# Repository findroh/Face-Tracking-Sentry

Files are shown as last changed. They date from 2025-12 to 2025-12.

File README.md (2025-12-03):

# Face-Tracking-Sentry
An automated sentry using a Raspberry Pi, ESP32, and two 9g servo motors along with a PiCamera 2 to perform facial detection, recognition, and tracking.
The control is split into two parts, image processing which is handled on the Raspberry Pi, and motor control which is handled by the ESP32-C3.
Due to the Raspberry Pi 4's relatively low processing power for tasks such as facial recognition, a finite state machine system is utilized to mitigate these issues.
The program initially starts in the detect state, which runs a continuous loop on standby until HaarCascades detects a face in the camera view. 
Once detection is achieved, the program then goes into the recognition state, this utilizes the facial recognition library to check the detected face against a file of pictures of labeled faces in the Pi's storage.
When recognition is completed an output of either the recognized faces name will be printed on the console, if the face is not recognized, "Unknown" will be printed on the console.
After this stage is completed, the system now goes to the Tracking state, this takes the same bounding box from the detection state and applies it as a boundary for a MOSSE tracker. 
The MOSSE tracker allows us to track a subjects face while also not losing our bounding box due to head movements such as turning the head to the side, up, or down.
The system will continue to stay in tracking mode until tracking is lost, which will cause the state machine to restart.
During the detection and tracking states, the coordinates of the center poitn of the bounding box are sent via USB serial communication to the EPS32.
These coordinates are used to calculate the error the bounding box to the center of the camera view.
I used this calculated error to control two servo motors in a PID control loop, with a seperate error calculation for the x and y axes. 
This allows the camera to have a quicker and more accurate response to the subject in the camera view.

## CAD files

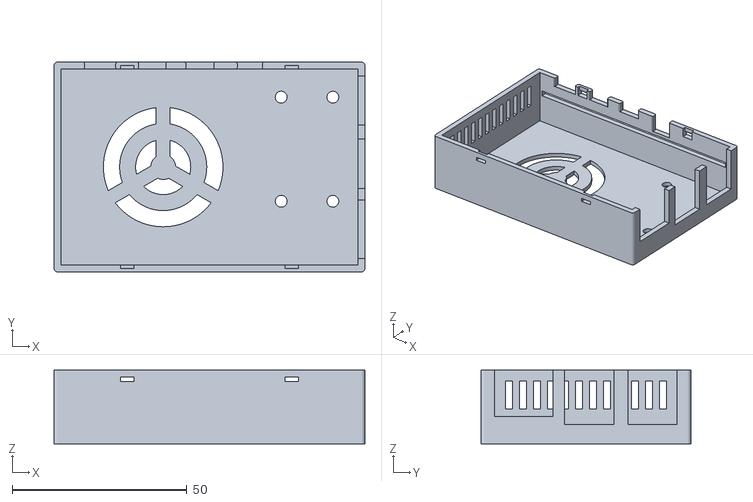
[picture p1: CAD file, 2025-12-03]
PiCase_Top.stl
89.0 x 60.0 x 21.1

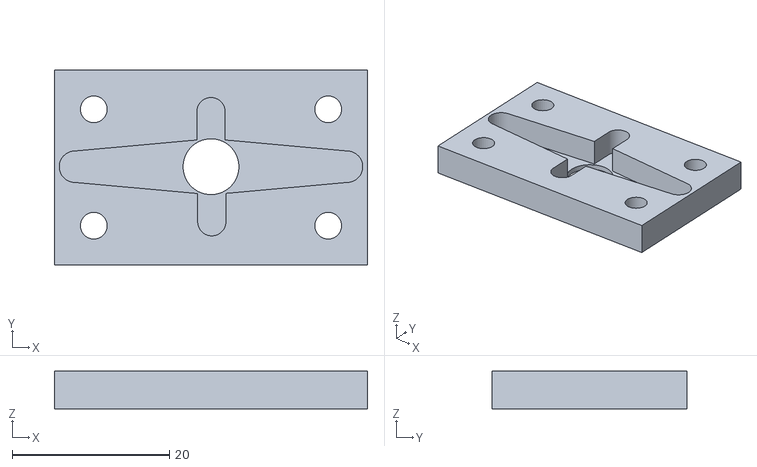
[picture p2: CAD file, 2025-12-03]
BasePlate_Revised.stl
39.8 x 24.8 x 4.80

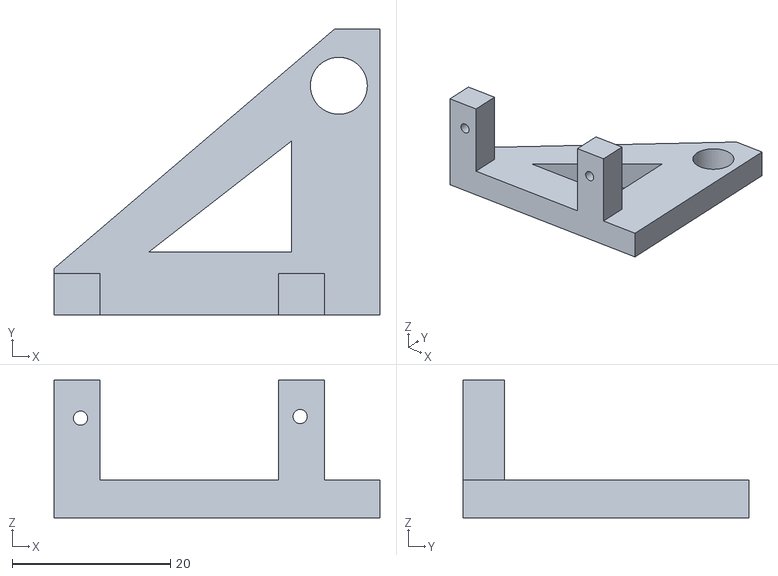
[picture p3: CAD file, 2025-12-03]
Mounting bracket V4.stl
41.2 x 36.2 x 17.4

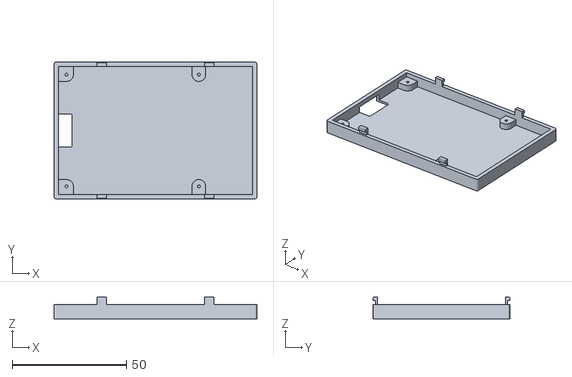
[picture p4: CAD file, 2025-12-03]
PiCaseBottom6-Fillet.stl
89.0 x 60.0 x 9.52

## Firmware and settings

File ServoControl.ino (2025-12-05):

#include <ESP32Servo.h>
#include <math.h>
Servo servoX;
Servo servoY;
int servoPinX = 6;
int servoPinY = 5;
int currentAngle_X = 90;
int currentAngle_Y = 90;
double Kp = 0.03;
double Ki = 0.0004;
double Kd = 0.5;
double dt = 0;
double previousTime = 0;
double integral = 0;
double previousError = 0;
void setup() {
  // put your setup code here, to run once:

 Serial.begin(115200);
 Serial.println("ESP32 Ready to Receive");
 servoX.attach(servoPinX);
 servoY.attach(servoPinY);
 servoX.write(currentAngle_X);
 servoY.write(currentAngle_Y);
  
}


void loop() {
  // put your main code here, to run repeatedly:
  
   if(Serial.available()){
    //servoX.write(65);
    //servoY.write(90);
    double currentTime = millis();
    dt = (currentTime - previousTime) / 1000;
    String receivedString = Serial.readStringUntil('\n');
    String receivedString2 = Serial.readStringUntil('\n');
    Serial.print("received integers");
    int receivedInt = receivedString.toInt();
    int receivedInt2 = receivedString2.toInt();
    Serial.println("Received Integers: ");
    Serial.println(receivedInt);
    Serial.println(receivedInt2);
    int x_error = receivedInt - 319;
    int y_error = receivedInt2 - 239;
    int X_Angle = currentAngle_X - pid(x_error);
    int Y_Angle = currentAngle_Y - pid(y_error);
    servoX.write(X_Angle);
    servoY.write(Y_Angle);
    
    }

    
}

int pid(int error){
  int proportional = error;
  integral = integral + (error * dt);
  double derivative = (error - previousError) / dt;
  //double output = (Kp * proportional) * (Ki * integral) + (Kd * derivative);
  //int myOutput = (int)ceil(output);
  previousError = error;
  double output = Kp * error + Ki * integral + Kd * derivative;
  return output;
  }

  

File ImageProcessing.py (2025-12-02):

import face_recognition
import cv2
from picamera2 import Picamera2
import time
import pickle
import numpy as np
import serial
ser = serial.Serial('/dev/ttyUSB0',115200, timeout = 1.0)
time.sleep(3)
ser.reset_input_buffer()
print("Serial OK")


# Load pre-trained face encodings
print("[INFO] loading encodings...")
with open("encodings.pickle", "rb") as f:
    data = pickle.loads(f.read())
known_face_encodings = data["encodings"]
known_face_names = data["names"]

cv_scaler = 1 # this has to be a whole number

face_locations = []
face_encodings = []
face_names = []
frame_count = 0
rec = 0
#start_time = time.time()
#fps = 0

# --- Camera ---
picam2 = Picamera2()
picam2.configure(
    picam2.create_preview_configuration(main={"format": "XRGB8888", "size": (640, 480)})
)
picam2.start()

# --- Haar detector ---
face_cascade = cv2.CascadeClassifier(
    cv2.data.haarcascades + "haarcascade_frontalface_default.xml"
)

authorized_names = ["john", "alice", "bob"]  # Replace with names you wish to authorise THIS IS CASE-SENSITIVE


def process_frame(frame):
    global face_locations, face_encodings, face_names
    
    # Resize the frame using cv_scaler to increase performance (less pixels processed, less time spent)
    resized_frame = cv2.resize(frame, (0, 0), fx=(1/cv_scaler), fy=(1/cv_scaler))
    
    # Convert the image from BGR to RGB colour space, the facial recognition library uses RGB, OpenCV uses BGR
    rgb_resized_frame = cv2.cvtColor(resized_frame, cv2.COLOR_BGR2RGB)
    
    # Find all the faces and face encodings in the current frame of video
    face_locations = face_recognition.face_locations(rgb_resized_frame)
    face_encodings = face_recognition.face_encodings(rgb_resized_frame, face_locations, model='large')
    
    face_names = []
    authorized_face_detected = False
    
    for face_encoding in face_encodings:
        # See if the face is a match for the known face(s)
        matches = face_recognition.compare_faces(known_face_encodings, face_encoding)
        name = "Unknown"
        print(name)
        # Use the known face with the smallest distance to the new face
        face_distances = face_recognition.face_distance(known_face_encodings, face_encoding)
        best_match_index = np.argmin(face_distances)
        if matches[best_match_index]:
            name = known_face_names[best_match_index]
            print(name)
            # Check if the detected face is in our authorized list
            if name in authorized_names:
                authorized_face_detected = True

        #face_names.append(name)
    
    # Control the GPIO pin based on face detection
    #if authorized_face_detected:
        #output.on()  # Turn on Pin
   # else:
   #     output.off()  # Turn off Pin
    print("frame processed")
#     print(name)

    return frame

def draw_results(frame):
    # Display the results
    for (top, right, bottom, left), name in zip(face_locations, face_names):
        # Scale back up face locations since the frame we detected in was scaled
        top *= cv_scaler
        right *= cv_scaler
        bottom *= cv_scaler
        left *= cv_scaler
        
        # Draw a box around the face
        cv2.rectangle(frame, (left, top), (right, bottom), (244, 42, 3), 3)
        
        # Draw a label with a name below the face
        cv2.rectangle(frame, (left -3, top - 35), (right+3, top), (244, 42, 3), cv2.FILLED)
        font = cv2.FONT_HERSHEY_DUPLEX
        cv2.putText(frame, name, (left + 6, top - 6), font, 1.0, (255, 255, 255), 1)
        # Add an indicator if the person is authorized
        if name in authorized_names:
            cv2.putText(frame, "Authorized", (left + 6, bottom + 23), font, 0.6, (0, 255, 0), 1)
    print("box drawn")
        #print(name)
    return frame

def detect_face_bbox(gray):
    faces = face_cascade.detectMultiScale(gray, scaleFactor=1.3, minNeighbors=5, minSize=(30, 30))
    if len(faces) == 0:
        return None
    # pick largest face (more stable)
    x, y, w, h = max(faces, key=lambda b: b[2] * b[3])
    #x, y, w, h = faces[0]
    return (int(x), int(y), int(w), int(h))

def create_mosse():
    #if hasattr(cv2, "legacy") and hasattr(cv2.legacy, "TrackerMOSSE_create"):
      return cv2.legacy.TrackerMOSSE_create()
#     return cv2.TrackerMOSSE_create() 

def sendCoordinates(x,y,w,h):
    x2 = x + (w / 2)
    y2 = y + (h / 2)
    ser.write(str(x2).encode('utf-8') + b'\n')
    ser.write(str(y2).encode('utf-8') + b'\n')
    print("Sent Coordinates: ", x2, y2)
    #time.sleep(1)
    return (int(x2), int(y2))

tracker = None
bbox = None
tracking = False

while True:
    # Picamera2 returns RGB; convert once for OpenCV trackers/drawing
    frame_rgb = picam2.capture_array()
    frame_bgr = cv2.cvtColor(frame_rgb, cv2.COLOR_RGB2BGR)
    frame_gray = cv2.cvtColor(frame_bgr, cv2.COLOR_BGR2GRAY)

    if not tracking:
        # Try to (re)detect
        found = detect_face_bbox(frame_gray)
        if found is not None:
            print(rec)
            if rec == 0:
                
                print("detected")
                process_frame(frame_rgb)
                
                draw_results(frame_rgb)
                
                #time.sleep(3)
                rec = 1 
                print(rec)
            bbox = found
            tracker = create_mosse()
            # IMPORTANT: init with the same 3-channel image type you'll use for update()
            tracker.init(frame_bgr, bbox)
            tracking = True
            # draw initial box for feedback
            x, y, w, h = bbox
            centerCoordinates = sendCoordinates(x,y,w,h)
            #cv2.circle(x2,y2,4, (0,0,255), -1)
            cv2.rectangle(frame_rgb, (x, y), (x + w, y + h), (0, 255, 0), 2)
            #cv2.circle(frame_rgb, centerCoordinates, 4, (0,0,255), -1)
            cv2.putText(frame_rgb, "Initialized MOSSE", (10, 30),
                        cv2.FONT_HERSHEY_SIMPLEX, 0.7, (0, 200, 0), 2)
        else:
            cv2.putText(frame_rgb, "Searching...", (10, 30),
                        cv2.FONT_HERSHEY_SIMPLEX, 0.7, (0, 0, 255), 2)

    else:
        # Already tracking -> just update
        ok, new_box = tracker.update(frame_bgr)
        if ok:
            x, y, w, h = map(int, new_box)
            bbox = (x, y, w, h)
            centerCoordinates = sendCoordinates(x,y,w,h)
            #cv2.circle(x2,y2,4, (0,0,255), -1)
            cv2.circle(frame_rgb, centerCoordinates, 4, (0,0,255), -1)

            cv2.rectangle(frame_rgb, (x, y), (x + w, y + h), (255, 0, 0), 2)
            cv2.putText(frame_rgb, "Tracking", (10, 30),
                        cv2.FONT_HERSHEY_SIMPLEX, 0.7, (255, 0, 0), 2)
        else:
            # Lost -> go back to detection next loop
            tracking = False
            tracker = None
            cv2.putText(frame_rgb, "Lost — re-scanning", (10, 30),
                        cv2.FONT_HERSHEY_SIMPLEX, 0.7, (0, 255, 255), 2)
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

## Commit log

2025-12-02 Create ImageProcessing.py
    This is code which allows the sentry to process the image from the Raspberry PiCam2. The code goes through the states: Searching, Detection, Recognition, Tracking. Make sure that the correct port for your microcontroller is written in the serial declaration statement on line 8.
    [ImageProcessing.py]
2025-12-02 ServoControl.ino
    This is a work in progress. Right now, the PID control factors are likely too large or the way I try to correct for error is flawed which leads to the motors overcorrecting and making the motors move far from the subject. I will upload the correct version when I sort these issues out.
    [ServoControl.ino]
2025-12-03 Add files via upload
    This includes mounting brackets for the X and Y axis servo motors as well as a modified Raspberry Pi Case that has a passthrough for the PiCamera 2 ribbon cable. The screw widths for the mounting bra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
    [BasePlate_Revised.stl, Mounting bracket V4.stl, PiCaseBottom6-Fillet.stl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]
